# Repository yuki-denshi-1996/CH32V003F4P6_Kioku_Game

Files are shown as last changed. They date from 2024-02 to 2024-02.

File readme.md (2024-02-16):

## 概要
CH32V003F4P6を用いた記憶ゲームです。  
オマケ機能として、1分刻みのタイマー機能も実装してあります。  

## 説明
赤ボタン(PD4)を押すと、ゲームスタートです。  
色と音がなりますので、順番を覚え、ボタンを押してください。  
間違えるとゲームオーバーとなります。  
この時、ハイスコアが更新された場合、ゲームスタート直後の数字のハイスコアが更新されます。  

黄色ボタン(PD7)を押しながら、赤ボタン(PD4)を押すと、ハイスコアがリセットされます。  
(この時、起動直後に7セグメントLEDにCと表示されます)  

黄色ボタン(PD7)を押しながら、青ボタン(PD6)を押すと、難易度の変更ができます。
1(簡単) ~ 9(難しい)まで調整できます。  

緑ボタン(PD5)を押すと、タイマーモードに移行します。  
タイマーモード中に赤ボタン(PD4)を押すことで、リセットされます。  
青ボタン(PD6)と黄色ボタン(PD7)で時間が設定できます。(1分~9分 1分刻み)    
時間を設定した後、緑ボタン(PD5)を押すと、タイマーがスタートします。  
タイマー終了後、緑ボタン(PD5)を押すと、音が停止します。  

## プログラムについて
MounRiver Studio V1.9.1で作成しています。  
User/Kioku_game_program.hに様々な宣言がされています。  
音の周波数などの定数を編集することなどが可能です。  

## 注意点
CH32V003F4P6のNRSTピンをIOピンとして使用してください。  
変更はWCH-LinkUtilityを使うと簡単です。  

## 回路図
回路図はCircuitフォルダにKiCad形式と画像形式で配布しています。  
ご活用ください。  
(基本的に回路図を変更しなければ、配布したプログラムを入れれば動作します)  

部品表は、PDF形式にて配布しています。  
基本的に、秋月電子通商様で手に入る部品を使用しています。

## 問題点について
簡単に自作したプログラムのため、プログラムが汚いです。ご了承ください。  
また、バグ等の問題があった場合、Issuesにお書きください。時間があるときに、修正します。  

## 再配布や使用について
バグ等、修正などができませんので、プログラムソースの再配布はお控えください。  

特にライセンス等を指定していませんが、自由に使用していただいて構いません。  
文化祭等での配布や、キット販売なども構いません。自由にお使いください。  
ただし、プログラムや回路図の使用に関しては、自己責任でお願い致します。  

不明点等有りましたら、下の連絡先までご連絡ください。(できるだけ早く返信します)  

## 連絡先
メールアドレス：matsukawa.software@gmail.com

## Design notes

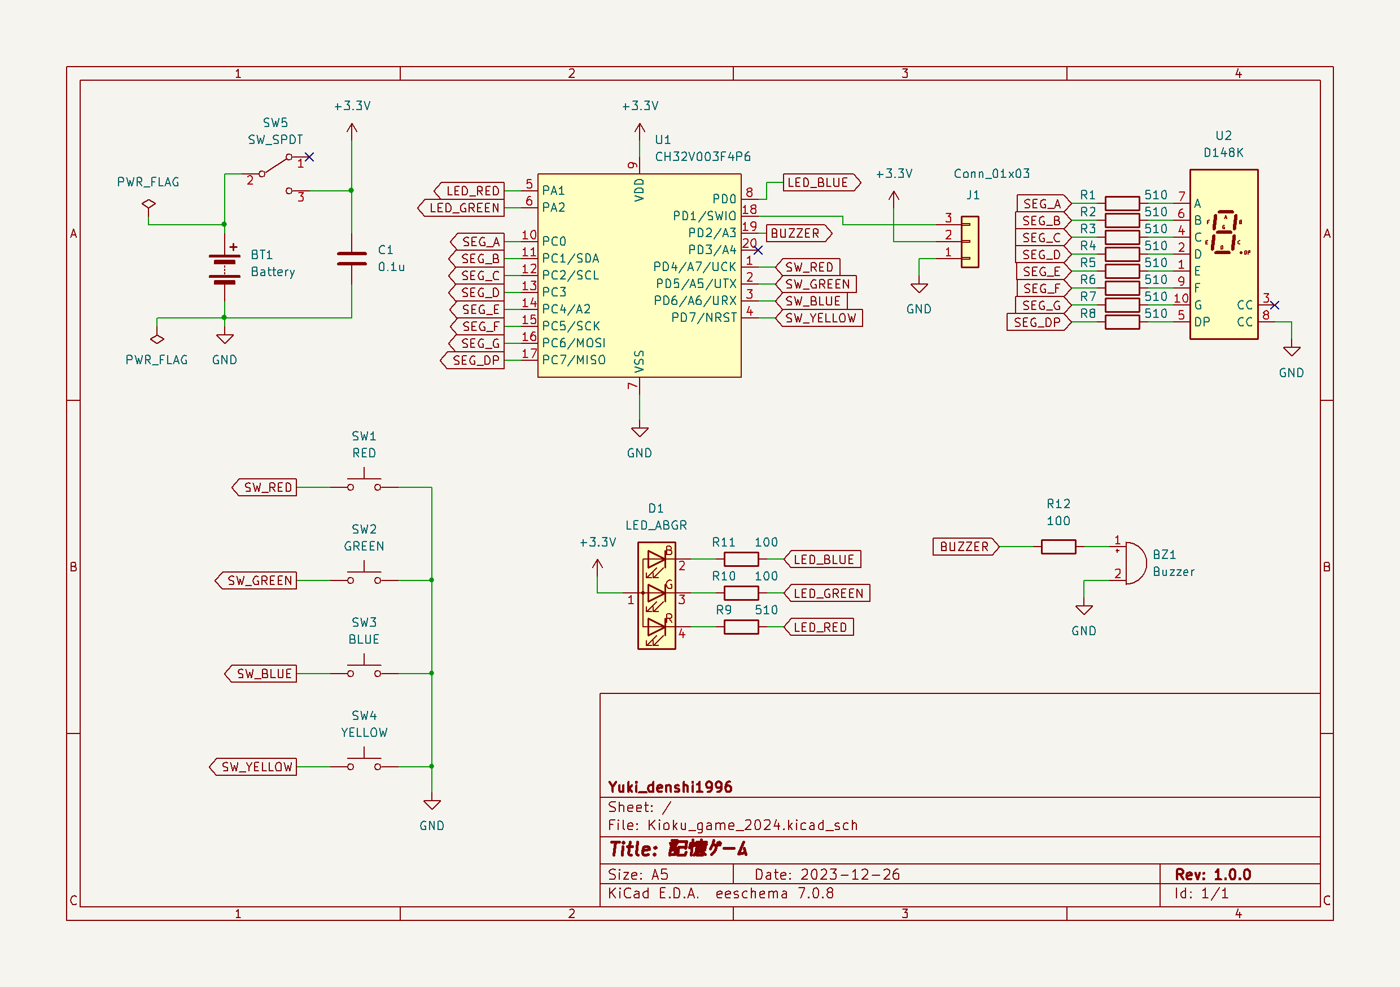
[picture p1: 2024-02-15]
Circuit/Kioku_game_2024/Circuit.png

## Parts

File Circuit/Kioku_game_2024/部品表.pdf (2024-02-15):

| 秋月_販売コード | 型番 | 個数
7セグメントLED カソードコモン | 100640 | C-551SRD | 1
CH32V003F4P6 | 118061 | | 1
角型フルカラーLED(RGBLED) アノードコモン | 116592 | OSTBMAZ2C1D | 1
ボタン電池基板取付用ホルダー CR2032用 | 100706 | CH25-2032LF | 1
タクトスイッチ(赤色) | 103646 | | 1
タクトスイッチ(黄色) | 103650 | | 1
タクトスイッチ(水色) | 103649 | | 1
タクトスイッチ(緑色) | 103651 | | 1
圧電スピーカー(圧電サウンダ)(13mm) | 104118 | PKM13EPYH4000-A0 | 1
積層セラミックコンデンサー 0.1μF50V X7R 2.54mm | 113582 | | 1
スライドスイッチ 1回路2接点 基板用 | 115707 | SS-12D00G3 | 1
カーボン抵抗(炭素皮膜抵抗) 1/4W1kΩ | 125102 | | 12
リチウム電池 CR2032 | 105694 | | 1

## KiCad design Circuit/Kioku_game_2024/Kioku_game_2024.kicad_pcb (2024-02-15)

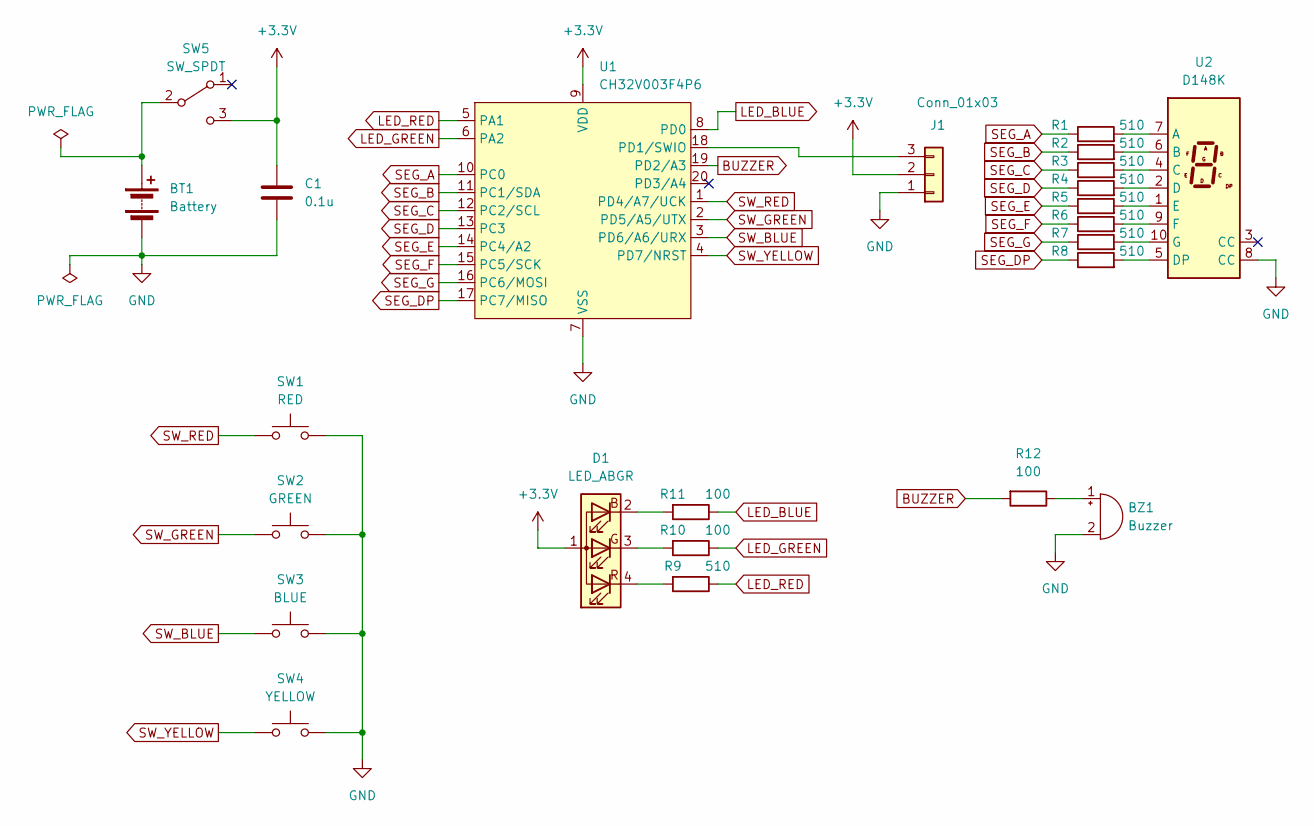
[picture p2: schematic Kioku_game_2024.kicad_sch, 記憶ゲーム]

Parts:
BT1: Battery; Coin_Cell_Batt_CR2032
BZ1: Buzzer; AKI_CERAMIC_BUZZER_PKM13EPYH4000-A0
C1: 0.1u; C_DISK_P5.0mm
D1: LED_ABGR; LED_BL-FL7680RGB
J1: Conn_01x03; PinSocket_1x03_P2.54mm_Vertical
R1, R2, R3, R4, R5, R6, R7, R8, R9: 510; R_1_4W
R10, R11, R12: 100; R_1_4W
SW1: RED; SW_PUSH_6mm
SW2: GREEN; SW_PUSH_6mm
SW3: BLUE; SW_PUSH_6mm
SW4: YELLOW; SW_PUSH_6mm
SW5: SW_SPDT; Yuki_PinHeader_1x03_P2.54mm_Vertical
U1: CH32V003F4P6; TSSOP-20_4.4x6.5mm_P0.65mm
U2: D148K; 7SegmentLED_LTS6760_LTS6780

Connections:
+3.3V: C1.1, D1.1 (A), J1.2, SW5.3 (C), U1.9 (VDD)
BUZZER: R12.2, U1.19 (PD2/A3)
GND: BT1.2 (-), BZ1.2 (+), C1.2, J1.1, SW1.2, SW2.2, SW3.2, SW4.2, U1.7 (VSS), U2.8 (CC)
LED_BLUE: R11.1, U1.8 (PD0)
LED_GREEN: R10.1, U1.6 (PA2)
LED_RED: R9.1, U1.5 (PA1)
unnamed: BT1.1 (+), SW5.2 (B)
unnamed: BZ1.1 (-), R12.1
unnamed: D1.2 (BK), R11.2
unnamed: D1.3 (GK), R10.2
unnamed: D1.4 (RK), R9.2
unnamed: J1.3, U1.18 (PD1/SWIO)
unnamed: R1.2, U2.7 (A)
unnamed: R2.2, U2.6 (B)
unnamed: R3.2, U2.4 (C)
unnamed: R4.2, U2.2 (D)
unnamed: R8.2, U2.5 (DP)
unnamed: R5.2, U2.1 (E)
unnamed: R6.2, U2.9 (F)
unnamed: R7.2, U2.10 (G)
SEG_A: R1.1, U1.10 (PC0)
SEG_B: R2.1, U1.11 (PC1/SDA)
SEG_C: R3.1, U1.12 (PC2/SCL)
SEG_D: R4.1, U1.13 (PC3)
SEG_DP: R8.1, U1.17 (PC7/MISO)
SEG_E: R5.1, U1.14 (PC4/A2)
SEG_F: R6.1, U1.15 (PC5/SCK)
SEG_G: R7.1, U1.16 (PC6/MOSI)
SW_BLUE: SW3.1, U1.3 (PD6/A6/URX)
SW_GREEN: SW2.1, U1.2 (PD5/A5/UTX)
SW_RED: SW1.1, U1.1 (PD4/A7/UCK)
SW_YELLOW: SW4.1, U1.4 (PD7/NRST)

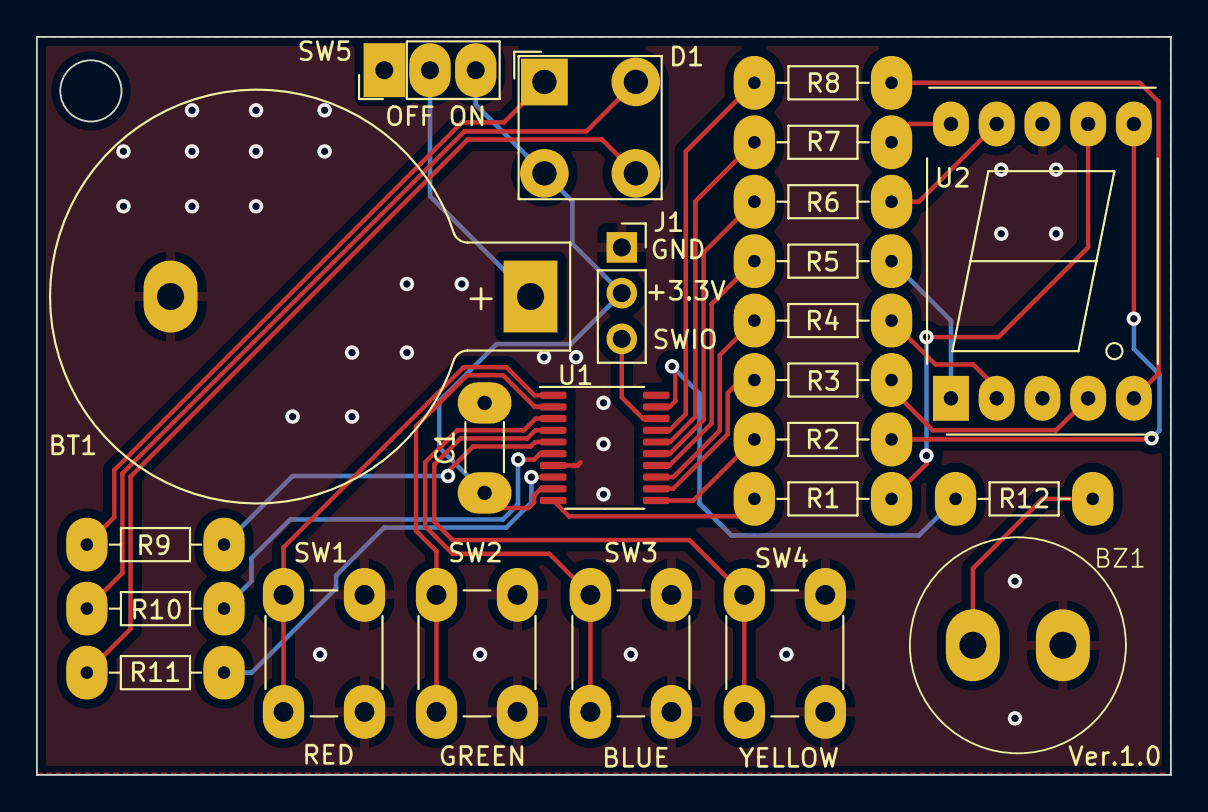
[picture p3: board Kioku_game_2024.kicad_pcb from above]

Board: 2 copper layers, 63.0 x 41.0 mm, 24 parts (0 on the bottom side), 32 nets.

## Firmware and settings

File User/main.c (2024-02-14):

/*
 *  記憶ゲーム V1.0
 *  2024/02/01
 *  Yuki (denshi-1996)
 */

#include <stdlib.h>
#include <ch32v00x.h>
#include "CH32V003F4P6_Mylib.h"
#include "Kioku_game_program.h"

#define DEBUG_MODE 0

void segment_print(int num, uint8_t wait);
void TIM2_IRQHandler(void) __attribute__((interrupt("WCH-Interrupt-fast")));
volatile unsigned int cnt1 = 0, cnt2 = 0, cnt3 = 0, cnt4 = 0, cnt5 = 0;
volatile unsigned int cnt6 = 0, cnt7 = 0, cnt8 = 0, cnt9 = 0, cnt10 = 0;
volatile int mode = MODE_START;

int main(void) {

    // 赤：1　緑：2　青：3　黄:4
    // 乱数で生成された点灯パターンが入る配列
    static unsigned char led_patt[1000] = { 0 };
    // スコア(どこまでいったか)(0からスタート)
    static int led_num = 0;
    // 入力時、何箇所目か
    static int led_num_now = 0;
    // 何色を入力したか
    static int push_led = 0;
    // 難易度用変数
    static int dif_wait_time;

    // タイマー時間
    static int timer_tim = 3;

    // メインクロックを8MHzに設定
    Clock_init_8MHz();
    // IOピン設定
    pin_init();
    // TIM2割り込み設定
    TIM2_interrupt_init();
    // TIM1 PWM1_CH1 PWM出力設定
    TIM1_PWM_init();

    // 初期状態で光らないように
    GPIOC->OUTDR = 0x00;
    GPIOA->OUTDR |= (1 << LED_BLUE);
    GPIOA->OUTDR |= (1 << LED_GREEN);
    GPIOD->OUTDR |= (1 << LED_RED);

    // 起動した時から、ボタン長押しを防ぐために、ボタンが離されるまで待機
    while ((GPIOD->INDR & (1 << SW_RED)) == 0)
    ;

    // フラッシュメモリが初期値の場合、リセット
    if (FLASH_read(HISCORE_FLASH) == 0xFFFF) {
        FLASH_write(HISCORE_FLASH, 0);
    }
    if (FLASH_read(DIF_TIME_FLASH) == 0xFFFF) {
        FLASH_write(DIF_TIME_FLASH, 5);
    }

    // 難易度
    switch (FLASH_read(DIF_TIME_FLASH)) {
    case 1:
        dif_wait_time = 1000;
        break;
    case 2:
        dif_wait_time = 850;
        break;
    case 3:
        dif_wait_time = 700;
        break;
    case 4:
        dif_wait_time = 600;
        break;
    case 5:
        dif_wait_time = 450;
        break;
    case 6:
        dif_wait_time = 400;
        break;
    case 7:
        dif_wait_time = 300;
        break;
    case 8:
        dif_wait_time = 200;
        break;
    case 9:
        dif_wait_time = 100;
        break;
    default:
        dif_wait_time = 500;
        break;
    }

    while (1)
    {
        switch (mode)
        {
            case MODE_START:
            // ボタンが押されるまで待機
            if (cnt1 >= 500)
            {
                cnt1 = 0;
                GPIOC->OUTDR ^= SEG_DOT;
            }
            // 乱数をランダムにするため
            rand();

            // 黄色＋青で難易度変更
            if ((GPIOD->INDR & (1 << SW_BLUE)) == 0 && (GPIOD->INDR & (1 << SW_YELLOW)) == 0)
            {
                // メモリから削除する関係で、一時的に保持
                int hiscore_temp = FLASH_read(HISCORE_FLASH);
                int dif_temp = FLASH_read(DIF_TIME_FLASH);
                dif_temp++;
                if (dif_temp >= 10)
                {
                    dif_temp = 1;
                }
                segment_print(dif_temp, 1);
                FLASH_Erase(HISCORE_FLASH);
                FLASH_write(HISCORE_FLASH, hiscore_temp);
                FLASH_write(DIF_TIME_FLASH, dif_temp);
                while ((GPIOD->INDR & (1 << SW_BLUE)) == 0 && (GPIOD->INDR & (1 << SW_YELLOW)) == 0)
                ;

                // 難易度
                switch (FLASH_read(DIF_TIME_FLASH))
                {
                    case 1:
                    dif_wait_time = 850;
                    break;
                    case 2:
                    dif_wait_time = 750;
                    break;
                    case 3:
                    dif_wait_time = 550;
                    break;
                    case 4:
                    dif_wait_time = 450;
                    break;
                    case 5:
                    dif_wait_time = 400;
                    break;
                    case 6:
                    dif_wait_time = 350;
                    break;
                    case 7:
                    dif_wait_time = 250;
                    break;
                    case 8:
                    dif_wait_time = 200;
                    break;
                    case 9:
                    dif_wait_time = 100;
                    break;
                    default:
                    dif_wait_time = 500;
                    break;
                }
            }

            // 黄色＋赤でハイスコアリセット
            if ((GPIOD->INDR & (1 << SW_RED)) == 0 && (GPIOD->INDR & (1 << SW_YELLOW)) == 0)
            {
                GPIOC->OUTDR &= ~SEG_DOT;
                int dif_temp = FLASH_read(DIF_TIME_FLASH);
                FLASH_Erase(HISCORE_FLASH);
                FLASH_write(DIF_TIME_FLASH, dif_temp);
                FLASH_write(HISCORE_FLASH, 0);
                segment_out_char('C');
                cnt1 = 0;
                while (cnt1 < 600)
                ;
                cnt1 = 0;
                mode = MODE_GAME_START;
            }
#if DEBUG_MODE
            if ((GPIOD->INDR & (1 << SW_GREEN)) == 0 && (GPIOD->INDR & (1 << SW_YELLOW)) == 0)
            {
                for (int i = 0; i <= 20; i++)
                {
                    led_patt[i] = i % 4 + 1;
                }
                led_num = 20;
            }
#endif
            // SW_REDが押されたら
            if ((GPIOD->INDR & (1 << SW_RED)) == 0)
            {
                GPIOC->OUTDR &= ~SEG_DOT;
                // モードをGAME_STARTに変更
                mode = MODE_GAME_START;
                cnt1 = 0;// MODE_GAME_STARTでも使用するため
            }
            // SW_GREENが押されたら
            if ((GPIOD->INDR & (1 << SW_GREEN)) == 0)
            {
                GPIOC->OUTDR &= ~SEG_DOT;
                // モードをTIMER_MODEに変更
                mode = MODE_TIMER_SELECT;

                tone(RED_BEEP);
                segment_print(timer_tim, 0);
                cnt2 = 0;
                while (cnt2 < 100)
                ;// チャタリング対策
                no_tone();
                cnt2 = 0;
                while ((GPIOD->INDR & (1 << SW_GREEN)) == 0)
                ;
                while (cnt2 < 100)
                ;// チャタリング対策

                cnt1 = 0;// MODE_GAME_STARTでも使用するため
            }
            break;
            case MODE_GAME_START:
            // ゲーム開始時のハイスコア表示 & 音,色確認
            if (cnt1 < 700)
            {
                segment_print(FLASH_read(HISCORE_FLASH), 1);
                cnt1 = 700;
            }
            if (cnt1 >= 700 && cnt1 < 1200)
            {
                GPIOA->OUTDR |= (1 << LED_BLUE);
                GPIOA->OUTDR |= (1 << LED_GREEN);
                GPIOD->OUTDR &= ~(1 << LED_RED);
                tone(RED_BEEP);
            }
            if (cnt1 >= 1200 && cnt1 < 1700)
            {
                GPIOA->OUTDR |= (1 << LED_BLUE);
                GPIOA->OUTDR &= ~(1 << LED_GREEN);
                GPIOD->OUTDR |= (1 << LED_RED);
                tone(GREEN_BEEP);
            }
            if (cnt1 >= 1700 && cnt1 < 2200)
            {
                GPIOA->OUTDR &= ~(1 << LED_BLUE);
                GPIOA->OUTDR |= (1 << LED_GREEN);
                GPIOD->OUTDR |= (1 << LED_RED);
                tone(BLUE_BEEP);
            }
            if (cnt1 >= 2200 && cnt1 < 2700)
            {
                GPIOA->OUTDR |= (1 << LED_BLUE);
                GPIOA->OUTDR &= ~(1 << LED_GREEN);
                GPIOD->OUTDR &= ~(1 << LED_RED);
                tone(YELLOW_BEEP);
            }
            if (cnt1 >= 2700 && cnt1 < 3200)
            {
                GPIOA->OUTDR |= (1 << LED_BLUE);
                GPIOA->OUTDR |= (1 << LED_GREEN);
                GPIOD->OUTDR |= (1 << LED_RED);
                no_tone();
            }
            if (cnt1 >= 3200)
            {
                mode = MODE_RANDOM;
            }
            break;
            case MODE_RANDOM:
            // 乱数を生成し、変数に格納するMode
            led_patt[led_num] = rand() % 4 + 1;
            cnt2 = 0;
            cnt3 = 0;
            led_num_now = 0;
            mode = MODE_LED_BEEP;
            break;
            case MODE_LED_BEEP:
            // 光とビーブオンを出力する
            if (led_patt[led_num_now] == RED)
            {
                GPIOA->OUTDR |= (1 << LED_BLUE);
                GPIOA->OUTDR |= (1 << LED_GREEN);
                GPIOD->OUTDR &= ~(1 << LED_RED);
                tone(RED_BEEP);
            }
            else if (led_patt[led_num_now] == GREEN)
            {
                GPIOA->OUTDR |= (1 << LED_BLUE);
                GPIOA->OUTDR &= ~(1 << LED_GREEN);
                GPIOD->OUTDR |= (1 << LED_RED);
                tone(GREEN_BEEP);
            }
            else if (led_patt[led_num_now] == BLUE)
            {
                GPIOA->OUTDR &= ~(1 << LED_BLUE);
                GPIOA->OUTDR |= (1 << LED_GREEN);
                GPIOD->OUTDR |= (1 << LED_RED);
                tone(BLUE_BEEP);
            }
            else if (led_patt[led_num_now] == YELLOW)
            {
                GPIOA->OUTDR |= (1 << LED_BLUE);
                GPIOA->OUTDR &= ~(1 << LED_GREEN);
                GPIOD->OUTDR &= ~(1 << LED_RED);
                tone(YELLOW_BEEP);
            }
            if (cnt3 >= dif_wait_time)
            {
                GPIOA->OUTDR |= (1 << LED_BLUE);
                GPIOA->OUTDR |= (1 << LED_GREEN);
                GPIOD->OUTDR |= (1 << LED_RED);
                no_tone();
                led_num_now++;
                while (cnt3 < dif_wait_time + 100)
                ;
                cnt2 = 0;
                cnt3 = 0;

                if (led_num_now > led_num)
                {
                    led_num_now = 0;
                    mode = MODE_WAIT;
                }
            }
            //            if(cnt2 > 500){
            //                cnt2 = 0;
            //                mode = MODE_WAIT;
            //                no_tone();
            //                GPIOA->OUTDR |= (1 << LED_BLUE);
            //                GPIOA->OUTDR |= (1 << LED_GREEN);
            //                GPIOD->OUTDR |= (1 << LED_RED);
            //            }
            break;
            case MODE_WAIT:
            // ボタンを押すまでの待ち時間
            // 赤が押されたら
            if ((GPIOD->INDR & (1 << SW_RED)) == 0)
            {
                GPIOA->OUTDR |= (1 << LED_BLUE);
                GPIOA->OUTDR |= (1 << LED_GREEN);
                GPIOD->OUTDR &= ~(1 << LED_RED);
                tone(RED_BEEP);
                push_led = RED;
                cnt2 = 0;
                while (cnt2 < 20)
                ; // チャタリング対策
                cnt2 = 0;
                while ((GPIOD->INDR & (1 << SW_RED)) == 0)
                ;
                mode = MODE_JUDGE;
            }
            // 緑が押されたら
            if ((GPIOD->INDR & (1 << SW_GREEN)) == 0)
            {
                GPIOA->OUTDR |= (1 << LED_BLUE);
                GPIOA->OUTDR &= ~(1 << LED_GREEN);
                GPIOD->OUTDR |= (1 << LED_RED);
                tone(GREEN_BEEP);
                push_led = GREEN;
                cnt2 = 0;
                while (cnt2 < 20)
                ; // チャタリング対策
                cnt2 = 0;
                while ((GPIOD->INDR & (1 << SW_GREEN)) == 0)
                ;
                mode = MODE_JUDGE;
            }
            // 青が押されたら
            if ((GPIOD->INDR & (1 << SW_BLUE)) == 0)
            {
                GPIOA->OUTDR &= ~(1 << LED_BLUE);
                GPIOA->OUTDR |= (1 << LED_GREEN);
                GPIOD->OUTDR |= (1 << LED_RED);
                tone(BLUE_BEEP);
                push_led = BLUE;
                cnt2 = 0;
                while (cnt2 < 20)
                ; // チャタリング対策
                cnt2 = 0;
                while ((GPIOD->INDR & (1 << SW_BLUE)) == 0)
                ;
                mode = MODE_JUDGE;
            }
            // 黄が押されたら
            if ((GPIOD->INDR & (1 << SW_YELLOW)) == 0)
            {
                GPIOA->OUTDR |= (1 << LED_BLUE);
                GPIOA->OUTDR &= ~(1 << LED_GREEN);
                GPIOD->OUTDR &= ~(1 << LED_RED);
                tone(YELLOW_BEEP);
                push_led = YELLOW;
                cnt2 = 0;
                while (cnt2 < 20)
                ; // チャタリング対策
                cnt2 = 0;
                while ((GPIOD->INDR & (1 << SW_YELLOW)) == 0)
                ;
                mode = MODE_JUDGE;
            }

            if (cnt2 < dif_wait_time * 2)
            {
                if (cnt7 > 400)
                {
                    GPIOC->OUTDR ^= SEG_DOT;
                    cnt7 = 0;
                }
            }
            if (cnt2 > dif_wait_time * 2 && cnt2 < dif_wait_time * 4)
            {
                if (cnt7 > 150)
                {
                    GPIOC->OUTDR ^= SEG_DOT;
                    cnt7 = 0;
                }
            }
            if (cnt2 > dif_wait_time * 4)
            {
                if (cnt7 > 50)
                {
                    GPIOC->OUTDR ^= SEG_DOT;
                    cnt7 = 0;
                }
            }
            if (cnt2 > dif_wait_time * 6)
            {
                GPIOC->OUTDR &= ~SEG_DOT;
                mode = MODE_GAMEOVER;
                cnt5 = 0;
            }

            break;
            case MODE_JUDGE:
            // 押された値が正しいか判断＆次に以降するか判断
            // すぐに判断せず、しばらくは光＆音を出力
            if (cnt2 >= (dif_wait_time - 20))
            {
                if (dif_wait_time < 200)
                {
                    cnt2 = 0;
                    while (cnt2 <= 100)
                    ; // 連続で認識してしまうため、待機
                }
                GPIOA->OUTDR |= (1 << LED_BLUE);
                GPIOA->OUTDR |= (1 << LED_GREEN);
                GPIOD->OUTDR |= (1 << LED_RED);
                no_tone();
                if (led_patt[led_num_now] == push_led)
                {
                    // 正解
                    led_num_now++;
                    cnt2 = 0;
                    cnt3 = 0;
                    mode = MODE_WAIT;

                    if (led_num_now > led_num)
                    {
                        mode = MODE_CLEAR_ONCE;
                        led_num++;
                        cnt4 = 0;
                    }
                }
                else
                {
                    // 不正解
                    mode = MODE_GAMEOVER;
                    cnt5 = 0;
                }
            }

            break;
            case MODE_CLEAR_ONCE:
            // クリアした場合
            segment_print(led_num, 1);
            cnt4 = 0;
            mode = MODE_CLEAR;
            break;
            case MODE_CLEAR:
            if (cnt4 > 500)
            {
                mode = MODE_RANDOM;
            }
            break;
            case MODE_GAMEOVER:
            // ゲームオーバー タイムアウト＆間違えた場合
            segment_print(led_num, 0);
            cnt5 = 0;
            // ハイスコア更新
            if (FLASH_read(HISCORE_FLASH) < led_num)
            {
                int dif_temp = FLASH_read(DIF_TIME_FLASH);
                FLASH_Erase(HISCORE_FLASH);
                FLASH_write(DIF_TIME_FLASH, dif_temp);
                FLASH_write(HISCORE_FLASH, led_num);
            }
            mode = MODE_GAMEOVER_RUN;
            break;

            case MODE_GAMEOVER_RUN:
            if (led_patt[led_num_now] == RED)
            {
                GPIOA->OUTDR |= (1 << LED_BLUE);
                GPIOA->OUTDR |= (1 << LED_GREEN);
                GPIOD->OUTDR &= ~(1 << LED_RED);
            }
            else if (led_patt[led_num_now] == GREEN)
            {
                GPIOA->OUTDR |= (1 << LED_BLUE);
                GPIOA->OUTDR &= ~(1 << LED_GREEN);
                GPIOD->OUTDR |= (1 << LED_RED);
            }
            else if (led_patt[led_num_now] == BLUE)
            {
                GPIOA->OUTDR &= ~(1 << LED_BLUE);
                GPIOA->OUTDR |= (1 << LED_GREEN);
                GPIOD->OUTDR |= (1 << LED_RED);
            }
            else if (led_patt[led_num_now] == YELLOW)
            {
                GPIOA->OUTDR |= (1 << LED_BLUE);
                GPIOA->OUTDR &= ~(1 << LED_GREEN);
                GPIOD->OUTDR &= ~(1 << LED_RED);
            }
            if (cnt5 > 100 && cnt5 < 200)
            {
                tone(GAMEOVER_BEEP1);
            }
            if (cnt5 >= 200 && cnt5 < 250)
            {
                no_tone();
            }
            if (cnt5 >= 250 && cnt5 < 500)
            {
                tone(GAMEOVER_BEEP2);
            }
            if (cnt5 > 700)
            {
                no_tone();
                GPIOA->OUTDR |= (1 << LED_BLUE);
                GPIOA->OUTDR |= (1 << LED_GREEN);
                GPIOD->OUTDR |= (1 << LED_RED);

                // mode = MODE_START;
                NVIC_SystemReset();
            }
            break;
            case MODE_TIMER_SELECT:
            if((GPIOD->INDR & (1 << SW_RED)) == 0) {
                NVIC_SystemReset();
            }

            // 青が押されたら
            if ((GPIOD->INDR & (1 << SW_BLUE)) == 0)
            {
                tone(TIMER_BEEP);
                timer_tim--;
                if (timer_tim <= 0)
                {
                    timer_tim = 9;
                }
                segment_print(timer_tim, 0);
                cnt2 = 0;
                while (cnt2 < 100)
                ; // チャタリング対策
                no_tone();
                cnt2 = 0;
                while ((GPIOD->INDR & (1 << SW_BLUE)) == 0)
                ;
                while (cnt2 < 100)
                ;// チャタリング対策
                cnt9 = 0;
            }

            // 黄が押されたら
            if ((GPIOD->INDR & (1 << SW_YELLOW)) == 0)
            {
                tone(TIMER_BEEP);
                timer_tim++;
                if (timer_tim >= 10)
                {
                    timer_tim = 1;
                }
                segment_print(timer_tim, 0);
                cnt2 = 0;
                while (cnt2 < 100)
                ; // チャタリング対策
                no_tone();
                cnt2 = 0;
                while ((GPIOD->INDR & (1 << SW_YELLOW)) == 0)
                ;
                while (cnt2 < 100)
                ;// チャタリング対策
                cnt9 = 0;
            }

            if ((GPIOD->INDR & (1 << SW_GREEN)) == 0)
            {
                mode = MODE_TIMER_SECTION;
                cnt8 = 0;
                cnt10 = 0;
                tone(TIMER_BEEP);
            }

            //segment_print(timer_tim, 0);

            if(cnt9 <= 500) {
                segment_out(timer_tim);
            }
            if(cnt9 > 500) {
                segment_out(-1);
            }
            if(cnt9 > 1000) {
                cnt9 = 0;
            }
            break;
            case MODE_TIMER_SECTION:
            if(cnt10 > 100) {
                no_tone();
            }

            if(cnt8 >= 60 * 1000) {
                timer_tim--;
                cnt8 = 0;
            }

            if (timer_tim <= 0)
            {
                mode = MODE_TIMER_END;
                cnt9 = 0;
                cnt10 = 0;
            }

            if(cnt9 <= 500) {
                GPIOC->OUTDR |= SEG_DOT;
            }
            if(cnt9 > 500) {
                GPIOC->OUTDR &= ~SEG_DOT;
            }
            if(cnt9 > 1000) {
                cnt9 = 0;
            }

            if((GPIOD->INDR & (1 << SW_RED)) == 0) {
                NVIC_SystemReset();
            }

            segment_out(timer_tim - 1);
            break;
            case MODE_TIMER_END:
            if (cnt9 < 75)
            {
                tone(TIMER_BEEP);
            }
            if (cnt9 >= 75 && cnt9 < 75 * 2)
            {
                no_tone();
            }
            if (cnt9 >= 75 * 2 && cnt9 < 75 * 3)
            {
                tone(TIMER_BEEP);
            }
            if (cnt9 >= 75 * 3 && cnt9 < 75 * 4)
            {
                no_tone();
            }
            if (cnt9 >= 75 * 4 && cnt9 < 75 * 5)
            {
                tone(TIMER_BEEP);
            }
            if (cnt9 >= 75 * 5 && cnt9 < 75 * 6)
            {
                no_tone();
            }
            if (cnt9 >= 75 * 6 && cnt9 < 75 * 7)
            {
                tone(TIMER_BEEP);
            }
            if (cnt9 >= 75 * 7 && cnt9 < 75 * 8)
            {
                no_tone();
            }
            if (cnt9 > 1000)
            {
                cnt9 = 0;
            }

            if(cnt10 < 500) {
                segment_out(0);
            }
            if(cnt10 >= 500) {
                segment_out(-1);
            }
            if(cnt10 > 1000) {
                cnt10 = 0;
            }

            if((GPIOD->INDR & (1 << SW_GREEN)) == 0) {
                no_tone();
                timer_tim = 3;
                mode = MODE_TIMER_SELECT;
                tone(RED_BEEP);
                cnt2 = 0;
                while (cnt2 < 100)
                ; // チャタリング対策
                no_tone();
                cnt2 = 0;
                while ((GPIOD->INDR & (1 << SW_YELLOW)) == 0)
                ;
                while (cnt2 < 100)
                ;// チャタリング対策
            }

            break;
        }
    }
}
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

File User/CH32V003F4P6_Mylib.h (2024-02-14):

/*
 * CH32V003F4P6_Mylib.h
 *
 *  Created on: Jan 21, 2024
 *      Author: Yuki(denshi-1996)
 */

#ifndef USER_CH32V003F4P6_MYLIB_H_
#define USER_CH32V003F4P6_MYLIB_H_

//入出力関係_定義
#define MODE_OUTPUT 0b11 //50MHz スピード OUTPUT
#define MODE_OUTPUT_2MHz 0b10
#define MODE_OUTPUT_10MHz 0b01
#define MODE_INPUT 0b00
#define CNF_INPUT_ANALOG 0b00
#define CNF_INPUT_FLOAT 0b01
#define CNF_INPUT_PULL 0b10
#define CNF_OUTPUT_PUSH_PULL 0b00
#define CNF_OUTPUT_OPEN_DRAIN 0b01
#define CNF_OUTPUT_FUNC_PUSH_PULL 0b10
#define CNF_OUTPUT_FUNC_OPEN_DRAIN 0b11

//ピン_定義
#define PA1 1
#define PA2 2
#define PC0 0
#define PC1 1
#define PC2 2
#define PC3 3
#define PC4 4
#define PC5 5
#define PC6 6
#define PC7 7
#define PD0 0
#define PD1 1
#define PD2 2
#define PD3 3
#define PD4 4
#define PD5 5
#define PD6 6
#define PD7 7


#define RA3 440
#define SI3 494
#define DO4 523
#define DO4S 554
#define RE4 587
#define MI4 659
#define FA4 698
#define SO4 794
#define RA4 440 * 2
#define SI4 494 * 2
#define DO5 523 * 2
#define RE5 587 * 2
#define MI5 659 * 2
#define FA5 698 * 2
#define SO5 794 * 2

//ユーザーオプション設定
int PD7_IO_Mode(void); //PD7を標準で使用
int PD7_NRST_Mode(void); //PD7をNRST(12ms typ)で使用

//クロック設定
void Clock_init_PLL(void);
void Clock_init_8MHz(void);

//入出力設定
void pin_init(void);

//Timer2 割り込み設定
void TIM2_interrupt_init(void);

//Timer1 PWM初期化設定
void TIM1_PWM_init(void);
//TIM1_PWMを用いたtone関数 (TIM1_CH1 PD2)
void tone(int freq);
//toneを止める関数
void no_tone(void);

//FLASH書き込み関数
void FLASH_write(uint32_t Address, uint16_t Data);
//FLASH読み出し関数
uint16_t FLASH_read(uint32_t Address);
//FLASH削除関数
void FLASH_Erase(volatile uint32_t Address);


//特定ビット置き換え関数(レジスタ操作特化)
uint32_t bit_replace(uint32_t data, uint32_t byte, uint8_t len, uint8_t shift);

#endif /* USER_CH32V003F4P6_MYLIB_H_ */

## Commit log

2024-02-14 [add] ファーストコミット
    ファーストコミット
2024-02-15 [Update] 微小な修正
2024-02-15 [Add] 回路データの追加
    回路図と基板例・部品表を追加
    [Kioku_game_2024.kicad_pcb, Kioku_game_2024.kicad_sch]
2024-02-16 [Update] readme.mdの編集
    readme.mdの微小な編集
